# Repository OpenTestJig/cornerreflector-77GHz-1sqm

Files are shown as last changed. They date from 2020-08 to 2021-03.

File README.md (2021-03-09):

RADAR corner reflector - 77GHz, 1 square meter
==============================================

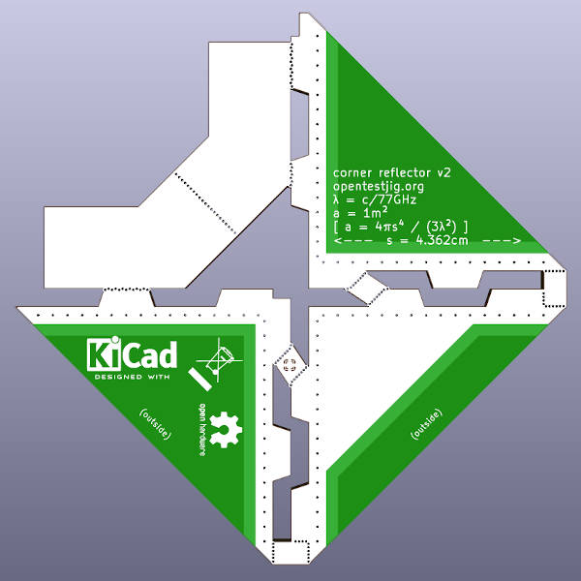
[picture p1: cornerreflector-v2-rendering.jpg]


* calculated to have a footprint of ~1m² at 77GHz
* simple and cheap design
* PCB based; order at your favourite PCB house
* some assembly required

Version Notes
-------------

# V1

Manufacturer complained that board connections need to be at least 5mm wide. Required change lead to V2.

# V2

Produced and works ok. Some assembly required. Supports mounting via a solderable (tinned) M8 nut.

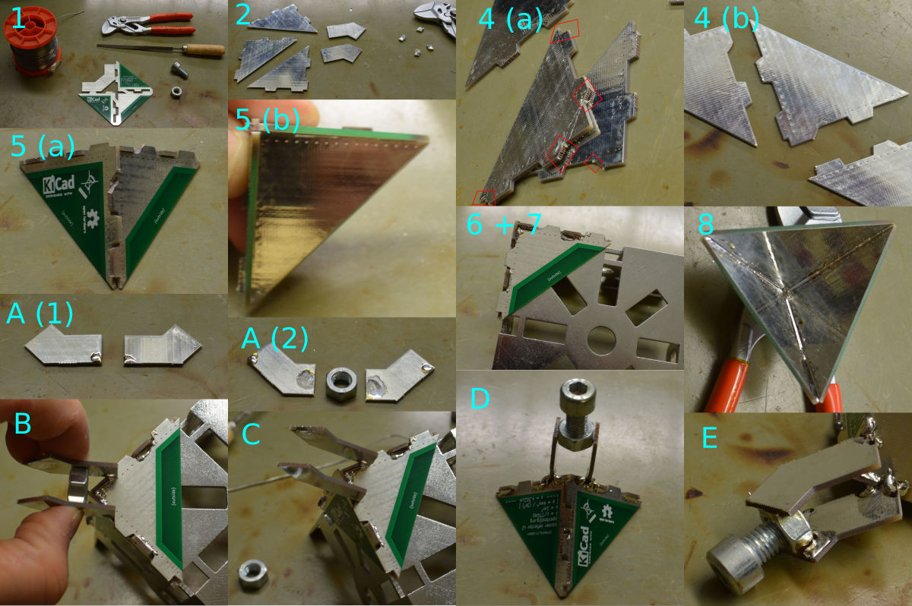
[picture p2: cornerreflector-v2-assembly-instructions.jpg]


## Assembly instructions

1) Gather parts: 1x PCB, flat file, plier, soldering iron & solder. If mouting bracket is needed: 1x tinned M8 NUT & tinned M8 screw.

2) Break boards into 9 pieces.

3) Discard the 4 tiny pieces.

4) Carefully file off the outer perforated edges of the main 3 reflector boards.

5) Test-wise assemble the three main pieces into a reflector and check that all reflective planes are rectangular to each other.

6) Place loosely assembled onto corner of a cube.

7) Solder all mechanical overhangs on the outside of the reflector.

8) Carefully solder inner edges with minimal amount of solder, as perfect as possible.

## Assembly of mounting bracket

Mounting bracket is designed for use with tinned M8 nut.

A) Deposit spare solder on mounting brackets where soldering is needed later.

B) While using the M8 nut as a mechanical spacer,

C) solder mounting bracket first to the reflector.

D) Then clamp M8 nut loosely between mounting pieces,

E) and solder the nut to the pieces.

## Proposed improvements for next version

* Perforation vias should be without copper (only mechanical holes, not vias).
* Copper planes should be removed from perforation areas.
* Perforations across each dimension should be aligned across one line. (Easier to break off.)
* Mounting pieces should be thinned towards the end.
* Perforations should be moved / reduced such that no edge-filing is needed.

License
-------

The design is released under the OSHW 1.0 license as defined
by [https://www.oshwa.org/definition/].

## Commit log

2020-08-10 version 1
    [reflektor.kicad_pcb, reflektor.sch]
2020-08-10 version 2: increase board-connections to at least 4mm
    [reflektor.kicad_pcb]
2020-08-19 version documentation, errata, assembly documentation
2020-08-20 add v2 assembly instructions
